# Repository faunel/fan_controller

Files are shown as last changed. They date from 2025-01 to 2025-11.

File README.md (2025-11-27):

English | [Українська](README.uk.md)

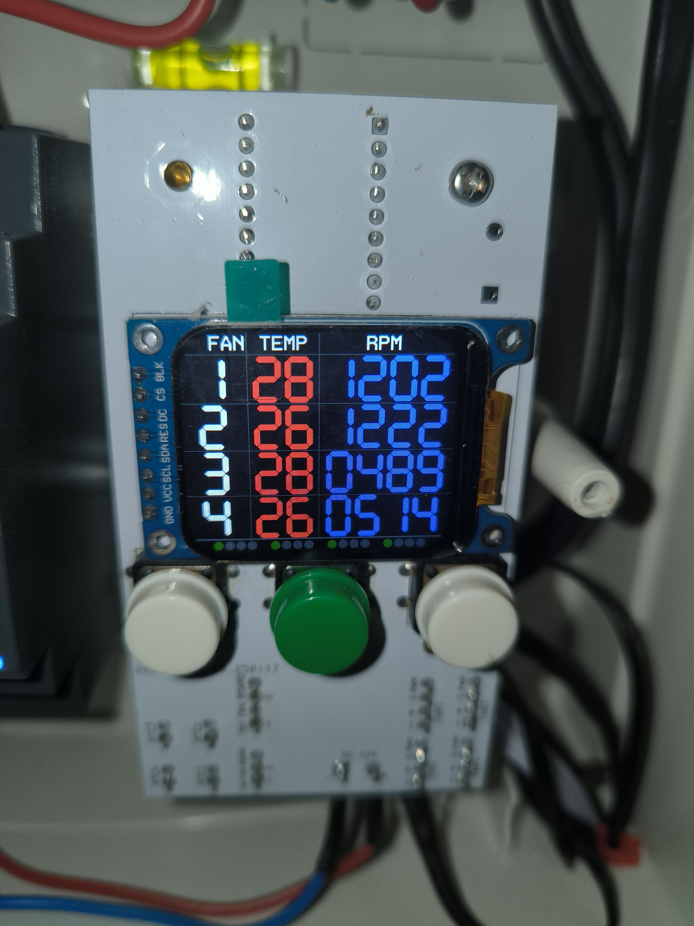
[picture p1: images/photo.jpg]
Fan Controller Board


# PWM Fan Controller Board

A control board for regulating fan speed using PWM (Pulse-Width Modulation).

## Overview

This board is designed to control up to four fans based on temperature readings from up to four NTC thermistors.  
It is intended, in particular, for use with hybrid inverters and includes an inverter fan emulation mode.

- Total output current: up to **5 A**, sufficient with a large margin for typical fans
- Temperature sensor type: **NTC 10 kΩ**
- Up to **4 fans** supported
- Up to **4 temperature sensors** supported
- **4 fan speed levels** depending on temperature
- **1 additional default speed** (used when temperature is below the first level)

## Fan–Sensor Mapping

Fan control logic is configurable in the menu:

- Any sensor can control any fan or group of fans
- All combinations are allowed

Examples:

- One sensor controls all 4 fans
- Two sensors:  
  - Sensor 1 controls fans 1–2  
  - Sensor 2 controls fans 3–4
- One sensor controls a single fan, another sensor controls the remaining three, etc.

The main menu displays for each fan/sensor:

- Temperature
- Fan speed (RPM)
- Current speed level (step)

## Hybrid Inverter Integration

The board is designed to work with a hybrid inverter and supports an **inverter fan emulation mode**.

- If the configuration allows the fans to be stopped (note: not all fans support full stop),
  the inverter will **not** generate a “fan stopped” error.
- Emulation is implemented by generating pulses at **300 Hz** on the signal (yellow) wire
  of the fan connector where the inverter’s original fan would normally be connected.

This corresponds to **9000 RPM** of the fan:

- 2 pulses per revolution  
- Formula: `300 / 2 * 60 = 9000`

### Fan Fault Handling

If the configuration requires a fan to rotate but it does not (for example):

- the connector is unplugged,
- the fan is blocked by a foreign object,
- the fan is defective,

then the inverter will detect an error and shut down until the cause is eliminated.  
This behaviour is intentional to prevent inverter overheating.

## Firmware / Development

### Flashing the firmware

```bash
cargo flash --chip stm32f411ceu6 --release
```

### Build and run with active terminal output

```bash
cargo run --release
```

### Build and detach from terminal

```bash
cargo embed --release
```

### Convert to HEX file

```bash
cargo-objcopy target/thumbv7em-none-eabihf/release/two --release -- -O ihex two.hex
```

### Disassembly

```bash
cargo objdump --bin two --release -- --disassemble --no-show-raw-insn --print-imm-hex
```

### Start OpenOCD

```bash
openocd -f interface/stlink.cfg -f target/stm32f4x.cfg
```

### Check program size

```bash
cargo size --bin fan_controller --release -- -A
```

## Memory Layout

### Program memory (Flash, base address: `0x08000000`)

- `.vector_table` – interrupt vector table, usually at the beginning of memory, containing addresses of interrupt handlers
- `.text` – section with program machine code (instructions)
- `.rodata` – section for constant, read-only data

### RAM (base address: `0x20000000`)

- `.data` – global and static variables initialized to specific values
- `.bss` – global and static variables initialized to zero
- `.uninit` – variables that are not initialized at program start

### Sections not included in the final binary / not critical for runtime

- `.gnu.sgstubs` – may contain special GNU-specific stubs
- `.ARM.attributes` – ARM-architecture-specific attributes
- `.comment` – comments or metadata
- `.defmt` – data for formatted output (e.g., for the `defmt` library)

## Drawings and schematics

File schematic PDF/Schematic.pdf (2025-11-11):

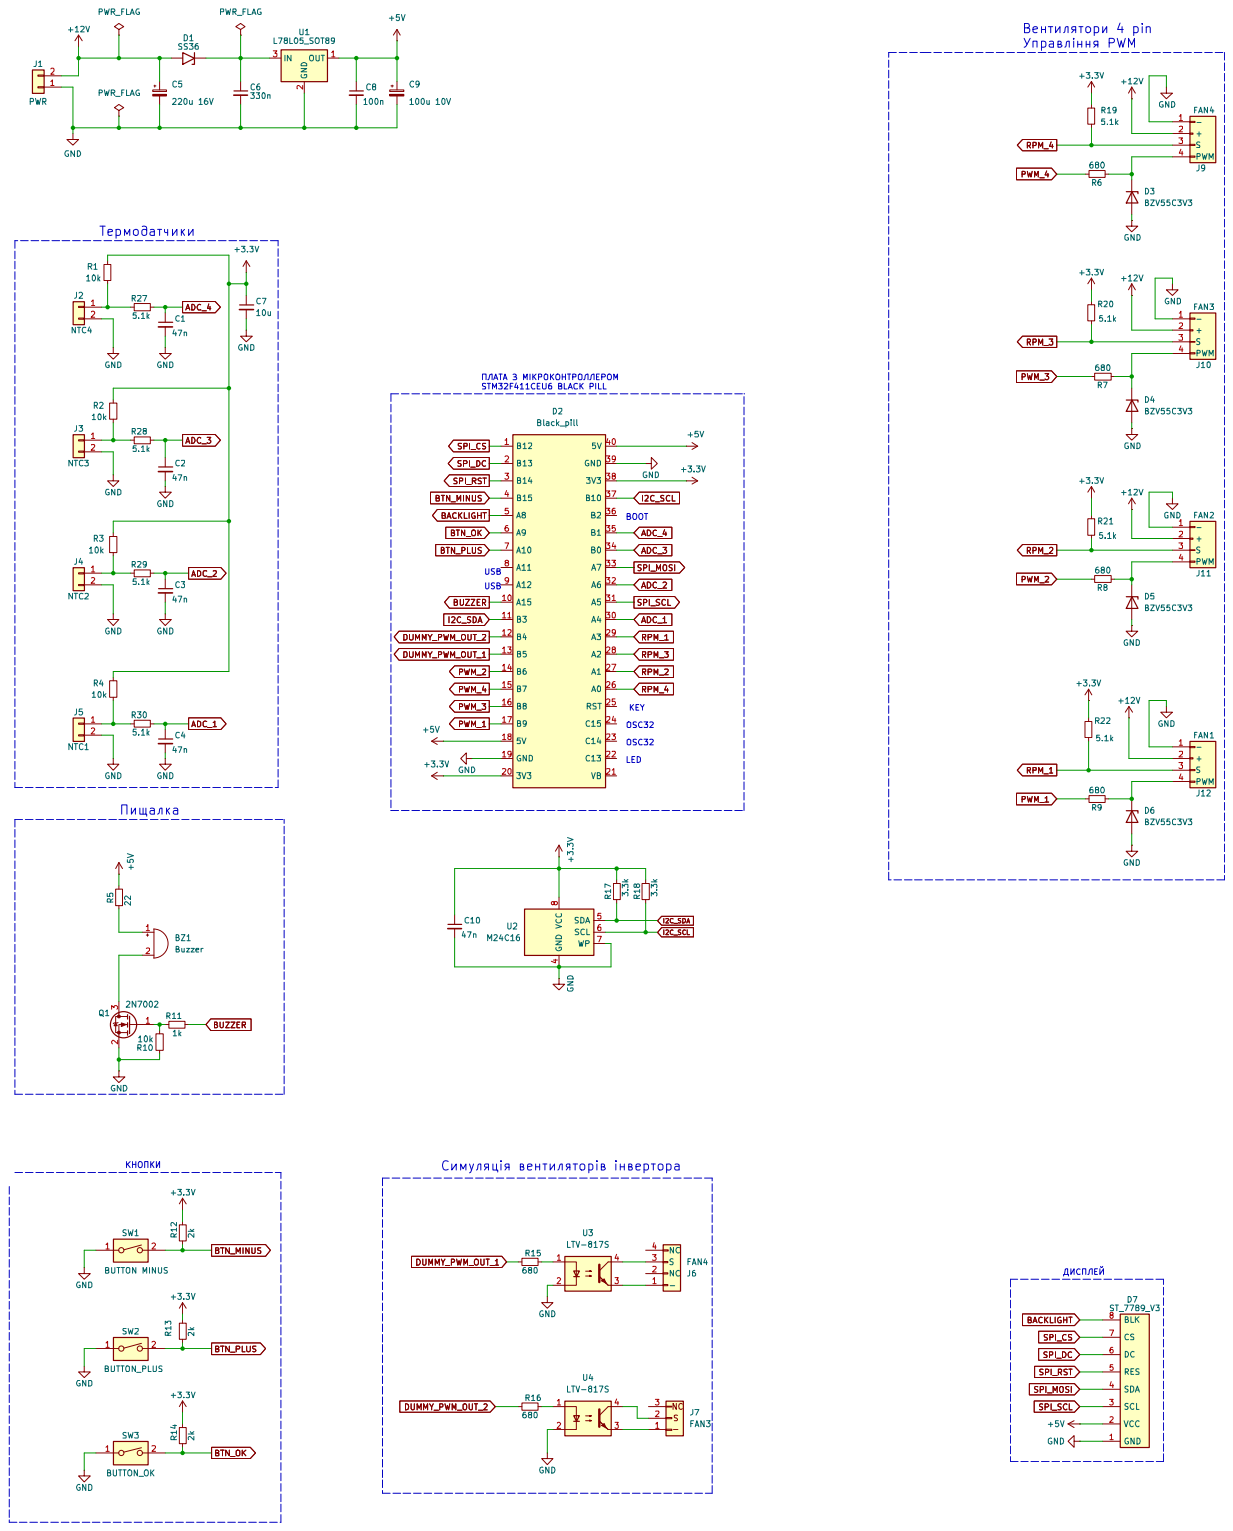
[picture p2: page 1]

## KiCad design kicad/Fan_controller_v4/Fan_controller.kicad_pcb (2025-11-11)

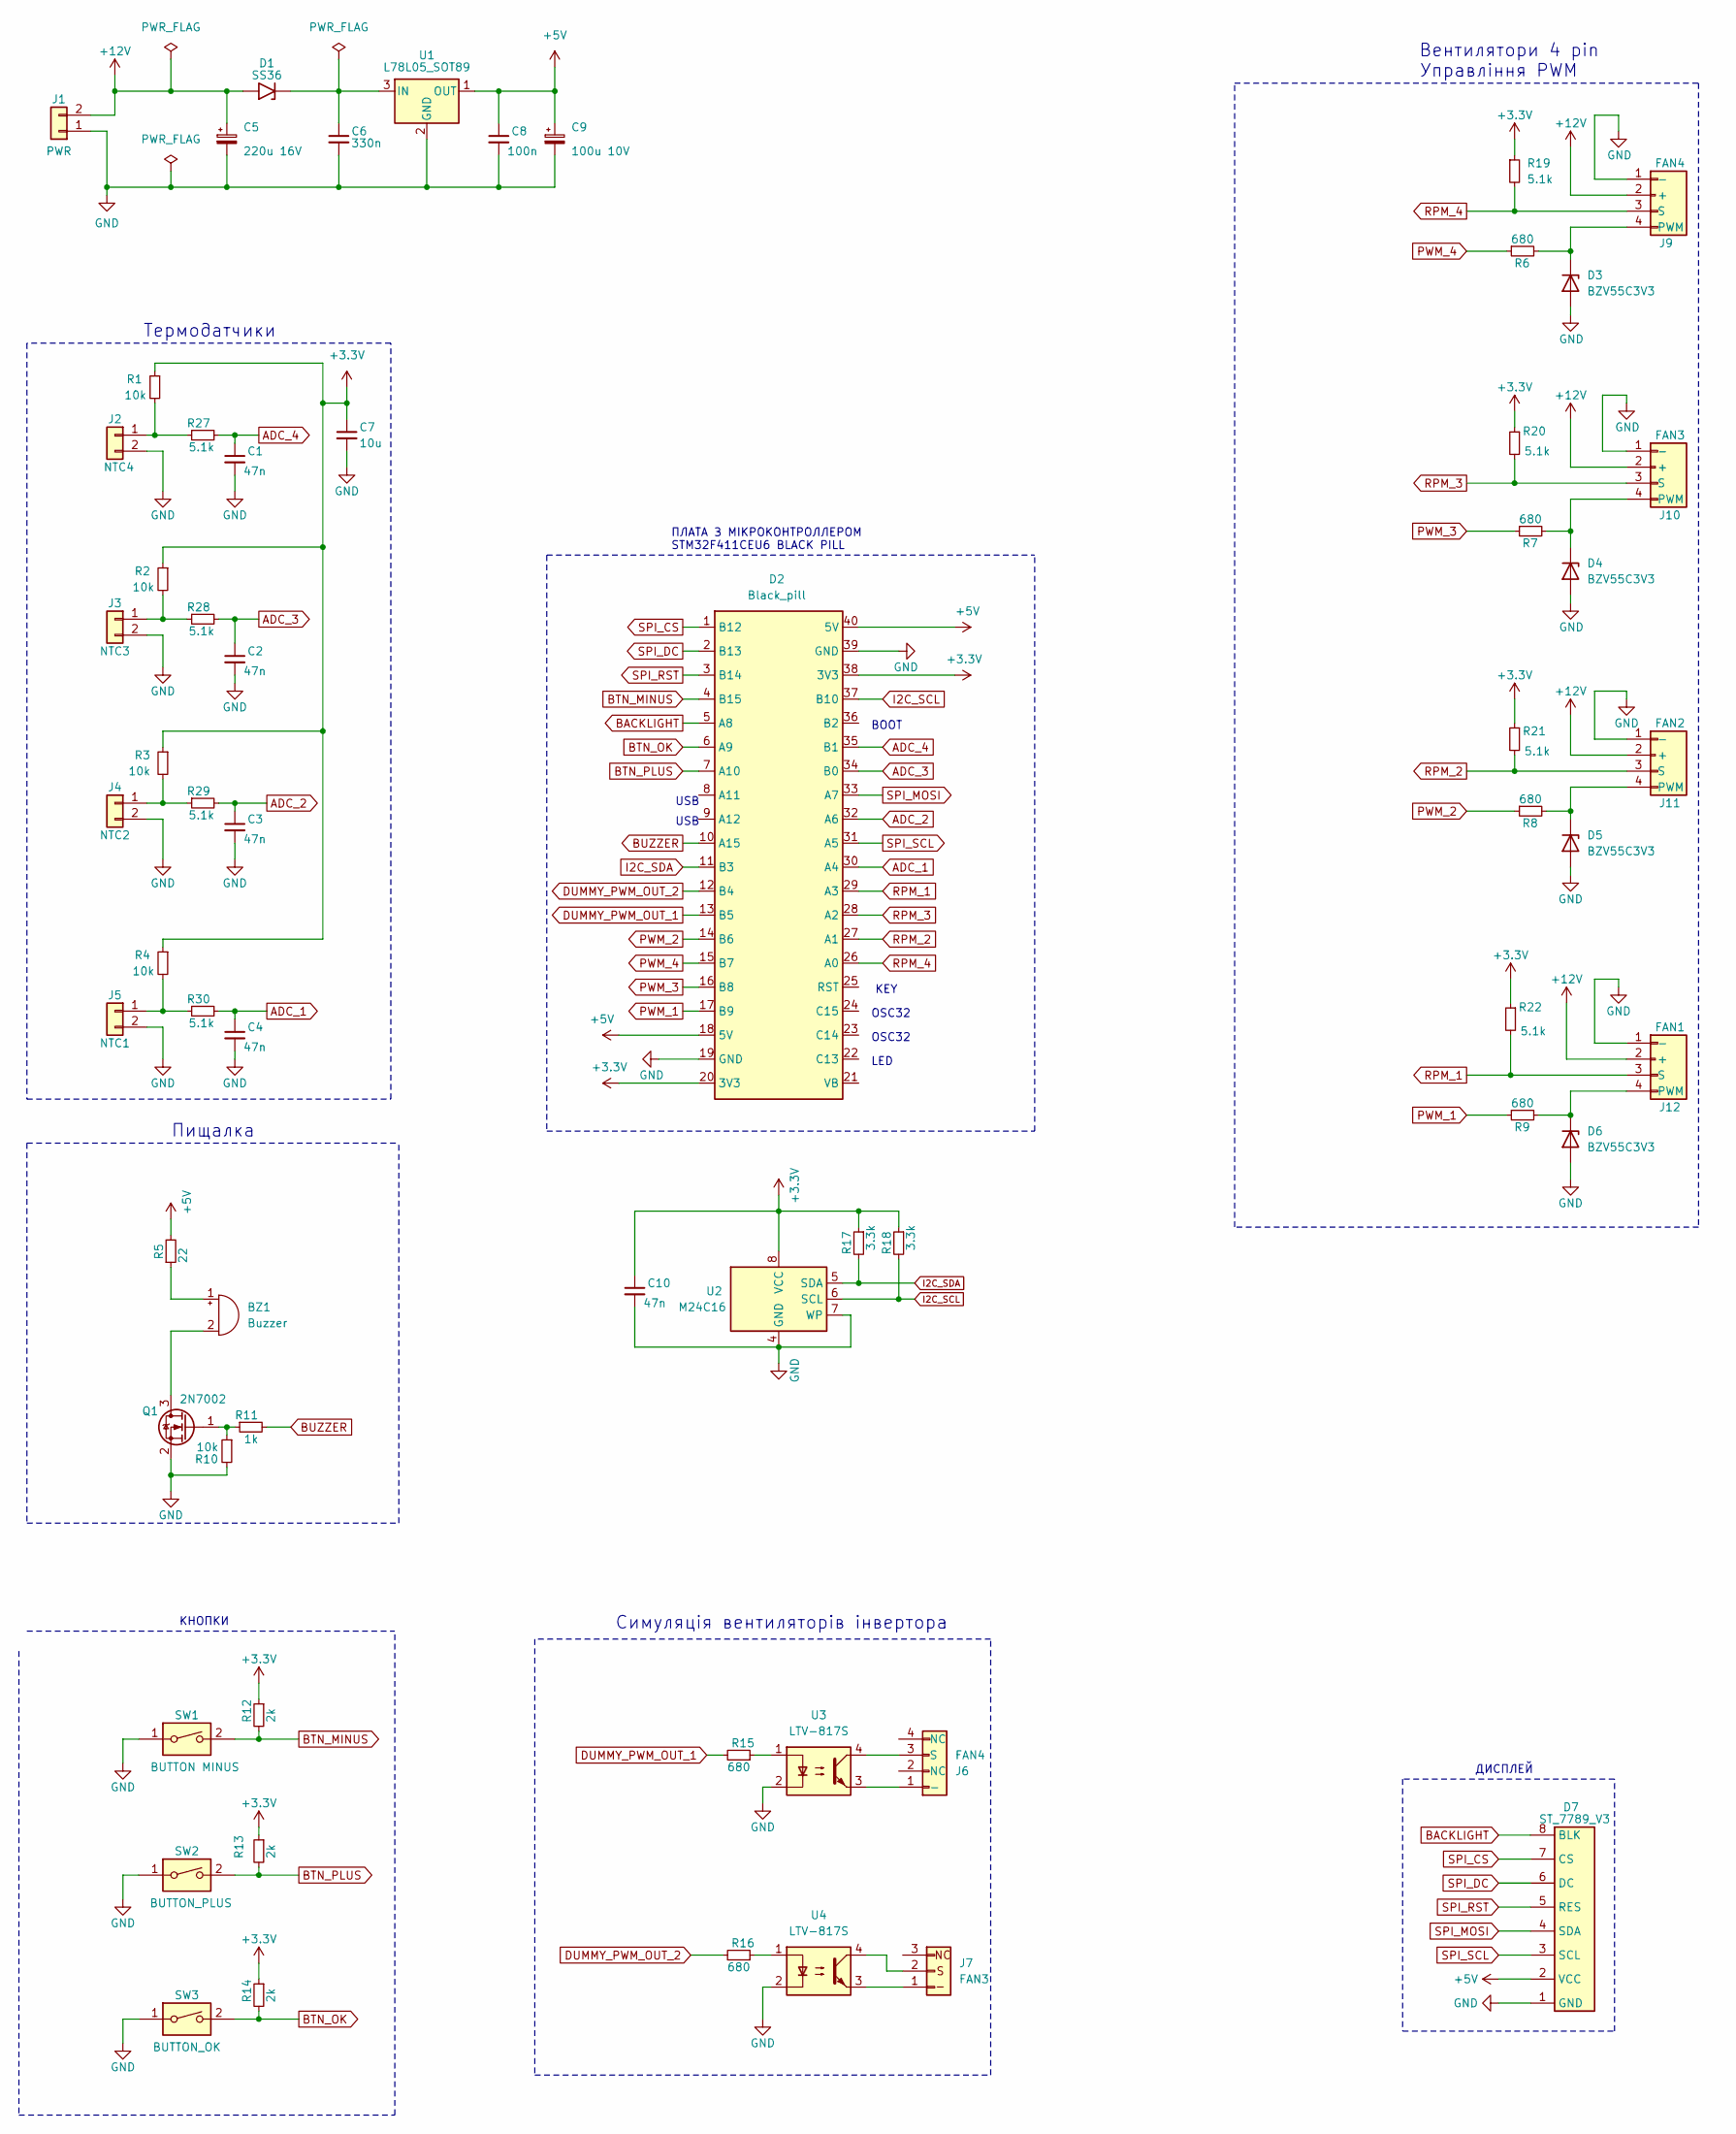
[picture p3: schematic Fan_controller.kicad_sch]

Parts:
BZ1: Buzzer; Buzzer_12x9.5RM7.6
C1, C2, C3, C4, C10: 47n; C_0805_2012Metric_Pad1.18x1.45mm_HandSolder
C5: 220u 16V; CP_Elec_6.3x7.7
C6: 330n; C_0805_2012Metric_Pad1.18x1.45mm_HandSolder
C7: 10u; C_0805_2012Metric_Pad1.18x1.45mm_HandSolder
C8: 100n; C_0805_2012Metric_Pad1.18x1.45mm_HandSolder
C9: 100u 10V; CP_Elec_5x5.4
D1: SS36; D_SMA-SMB_Universal_Handsoldering
D2: Black_pill
D3, D4, D5, D6: BZV55C3V3; D_SOD-123
D7: ST_7789_V3
J1: PWR; TerminalBlock_MetzConnect_Type094_RT03502HBLU_1x02_P5.00mm_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
J2: NTC4; JST_XH_B2B-XH-A_1x02_P2.50mm_Vertical
J3: NTC3; JST_XH_B2B-XH-A_1x02_P2.50mm_Vertical
J4: NTC2; JST_XH_B2B-XH-A_1x02_P2.50mm_Vertical
J5: NTC1; JST_XH_B2B-XH-A_1x02_P2.50mm_Vertical
J6: FAN4; JST_XH_B4B-XH-A_1x04_P2.50mm_Vertical
J7: FAN3; JST_XH_B3B-XH-A_1x03_P2.50mm_Vertical
J9: FAN4; FanPinHeader_1x04_P2.54mm_Vertical
J10: FAN3; FanPinHeader_1x04_P2.54mm_Vertical
J11: FAN2; FanPinHeader_1x04_P2.54mm_Vertical
J12: FAN1; FanPinHeader_1x04_P2.54mm_Vertical
Q1: 2N7002; SOT-23
R1, R2, R3, R4, R10: 10k; R_0805_2012Metric_Pad1.20x1.40mm_HandSolder
R5: 22; R_0805_2012Metric_Pad1.20x1.40mm_HandSolder
R6, R7, R8, R9, R15, R16: 680; R_0805_2012Metric_Pad1.20x1.40mm_HandSolder
R11: 1k; R_0805_2012Metric_Pad1.20x1.40mm_HandSolder
R12, R13, R14: 2k; R_0805_2012Metric_Pad1.20x1.40mm_HandSolder
R17, R18: 3.3k; R_0805_2012Metric_Pad1.20x1.40mm_HandSolder
R19, R20, R21, R22, R27, R28, R29, R30: 5.1k; R_0805_2012Metric_Pad1.20x1.40mm_HandSolder
SW1: BUTTON MINUS; SW_PUSH-12mm
SW2: BUTTON_PLUS; SW_PUSH-12mm
SW3: BUTTON_OK; SW_PUSH-12mm
U1: L78L05_SOT89; SOT-89-3
U2: M24C16; SOIC-8_3.9x4.9mm_P1.27mm
U3, U4: LTV-817S; SMDIP-4_W9.53mm

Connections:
+3.3V: C7.1, C10.1, D2.20 (3V3), D2.38 (3V3), R1.1, R2.1, R3.1, R4.1, R12.1, R13.1, R14.1, R17.1, R18.1, R19.1, R20.1, R21.1, R22.1, U2.8 (VCC)
+5V: C8.1, C9.1, D2.18 (5V), D2.40 (5V), D7.2 (VCC), R5.2, U1.1 (OUT)
+12V: C5.1, D1.2 (A2), J1.2, J9.2 (+), J10.2 (+), J11.2 (+), J12.2 (+)
ADC_1: C4.1, D2.30 (A4), R30.2
ADC_2: C3.1, D2.32 (A6), R29.2
ADC_3: C2.1, D2.34 (B0), R28.2
ADC_4: C1.1, D2.35 (B1), R27.2
BACKLIGHT: D2.5 (A8), D7.8 (BLK)
BTN_MINUS: D2.4 (B15), R12.2, SW1.2
BTN_OK: D2.6 (A9), R14.2, SW3.2
BTN_PLUS: D2.7 (A10), R13.2, SW2.2
BUZZER: D2.10 (A15), R11.2
DUMMY_PWM_OUT_1: D2.13 (B5), R15.2
DUMMY_PWM_OUT_2: D2.12 (B4), R16.2
GND: C1.2, C2.2, C3.2, C4.2, C5.2, C6.2, C7.2, C8.2, C9.2, C10.2, D2.19 (GND), D2.39 (GND), D3.2 (A), D4.2 (A), D5.2 (A), D6.2 (A), D7.1 (GND), J1.1, J2.2, J3.2, J4.2, J5.2, J9.1 (-), J10.1 (-), J11.1 (-), J12.1 (-), Q1.2 (S), R10.2, SW1.1, SW2.1, SW3.1, U1.2 (GND), U2.4 (GND), U2.7 (WP), U3.2, U4.2
I2C_SCL: D2.37 (B10), R18.2, U2.6 (SCL)
I2C_SDA: D2.11 (B3), R17.2, U2.5 (SDA)
unnamed: BZ1.2 (+), Q1.3 (D)
unnamed: BZ1.1 (-), R5.1
unnamed: C6.1, D1.1 (A1), U1.3 (IN)
unnamed: D3.1 (K), J9.4 (PWM), R6.2
unnamed: D4.1 (K), J10.4 (PWM), R7.2
unnamed: D5.1 (K), J11.4 (PWM), R8.2
unnamed: D6.1 (K), J12.4 (PWM), R9.2
unnamed: J2.1, R1.2, R27.1
unnamed: J3.1, R2.2, R28.1
unnamed: J4.1, R3.2, R29.1
unnamed: J5.1, R4.2, R30.1
unnamed: J6.1 (-), U3.3
unnamed: J6.3 (S), U3.4
unnamed: J7.1 (NC), U4.3
unnamed: J7.2, U4.4
unnamed: Q1.1 (G), R10.1, R11.1
unnamed: R15.1, U3.1
unnamed: R16.1, U4.1
PWM_1: D2.17 (B9), R9.1
PWM_2: D2.14 (B6), R8.1
PWM_3: D2.16 (B8), R7.1
PWM_4: D2.15 (B7), R6.1
RPM_1: D2.29 (A3), J12.3 (S), R22.2
RPM_2: D2.27 (A1), J11.3 (S), R21.2
RPM_3: D2.28 (A2), J10.3 (S), R20.2
RPM_4: D2.26 (A0), J9.3 (S), R19.2
SPI_CS: D2.1 (B12), D7.7 (CS)
SPI_DC: D2.2 (B13), D7.6 (DC)
SPI_MOSI: D2.33 (A7), D7.4 (SDA)
SPI_RST: D2.3 (B14), D7.5 (RES)
SPI_SCL: D2.31 (A5), D7.3 (SCL)

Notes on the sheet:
OSC32
ДИСПЛЕЙ
USB
КНОПКИ
ПЛАТА З МІКРОКОНТРОЛЛЕРОМ STM32F411CEU6 BLACK PILL
KEY
LED
Пищалка
Вентилятори 4 pin Управління PWM
BOOT
Симуляція вентиляторів інвертора
Термодатчики

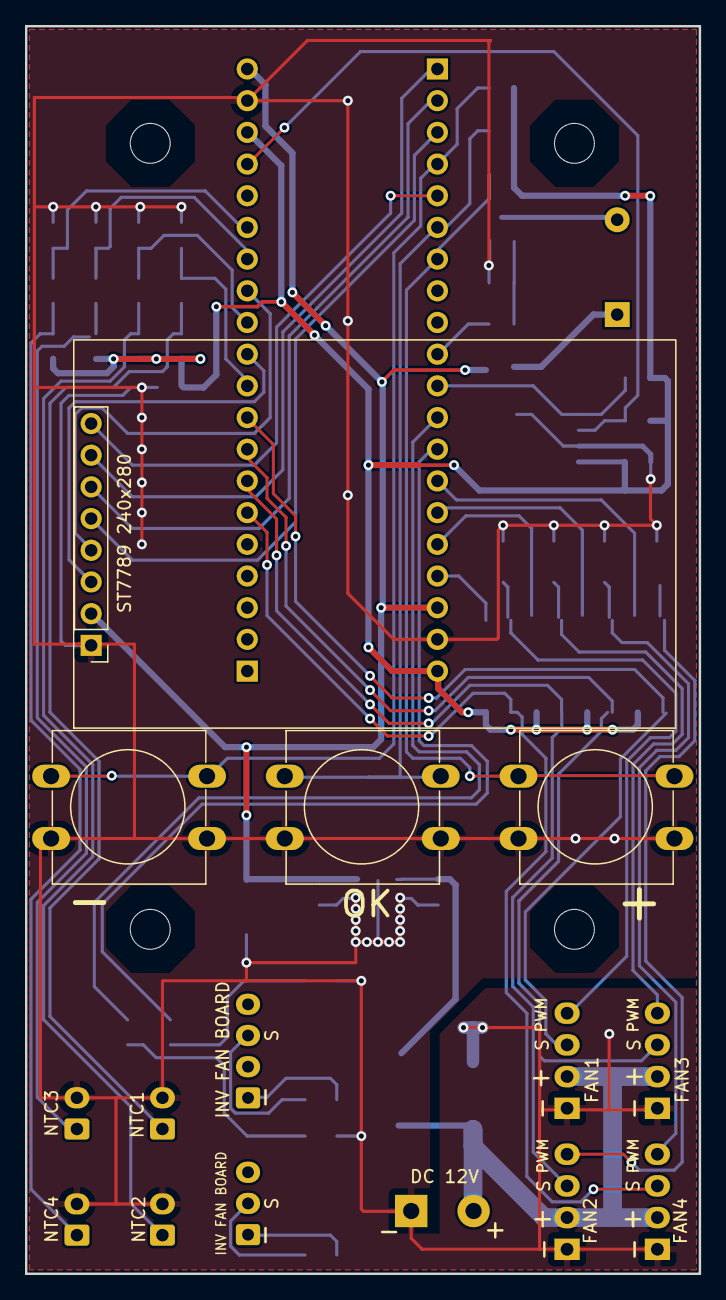
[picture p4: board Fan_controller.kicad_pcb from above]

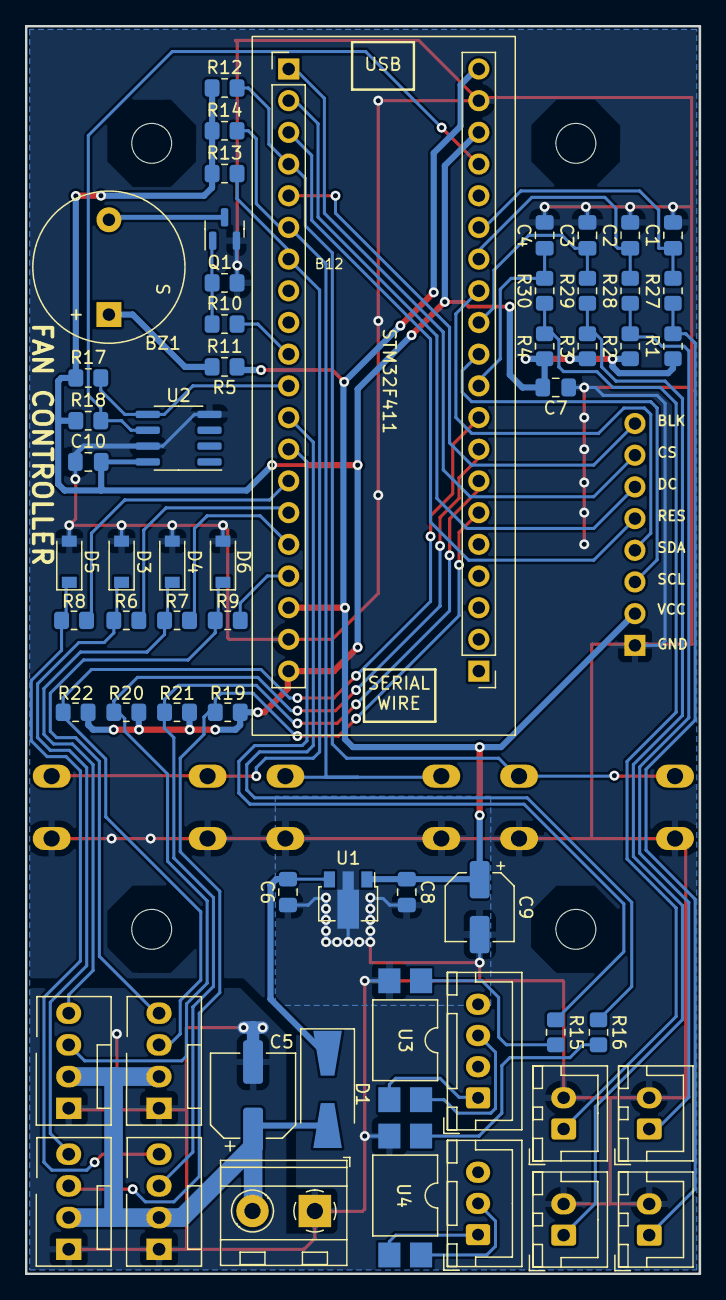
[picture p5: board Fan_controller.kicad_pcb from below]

Board: 2 copper layers, 54.0 x 100.0 mm, 63 parts (59 on the bottom side), 48 nets.

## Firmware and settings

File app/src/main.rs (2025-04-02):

#![no_main]
#![no_std]
// #![allow(unused)]

#[rtic::app(device = stm32f4xx_hal::pac, dispatchers = [SPI2, SPI3, SPI4])]
mod app {
    use async_button::prelude::*;
    // use cortex_m::asm;
    // #[allow(unused)]
    use defmt::info;
    // use display_interface_spi::SPIInterface;
    use eeprom::eeprom::{Settings, EEPROM};
    use embassy_futures::select::{select3, Either3};
    use embedded_alloc::LlffHeap as Heap;
    use embedded_hal::digital::InputPin;
    use embedded_hal_bus::spi::ExclusiveDevice;
    use measurements::{
        control::Control,
        measure::{AdcMeasure, Data, MeasureConfig, RpmData, RpmState},
        ADC_BUFFER,
    };
    use mipidsi::interface::SpiInterface;
    use mipidsi::{models::ST7789, options::ColorInversion};
    use mipidsi::{
        // interface::SpiError as DisplayError,
        // s::Error as DisplayError,
        options::{ColorOrder, Orientation, Rotation},
        Builder,
    };
    use monotonic::prelude::*;
    use ntc::Ntc;
    use rclite::Rc;
    extern crate alloc;
    use defmt_rtt as _;
    use panic_probe as _;
    use spin::rwlock::RwLock;
    #[allow(unused)]
    use stm32f4xx_hal::pac::DWT;
    use stm32f4xx_hal::{
        adc::{
            config::{AdcConfig, Clock, Continuous, Dma, Resolution, SampleTime, Scan, Sequence},
            Adc,
        },
        dma::{config::DmaConfig, PeripheralToMemory, Stream0, StreamsTuple, Transfer},
        gpio::{Pin, Speed},
        hal::pwm::SetDutyCycle,
        i2c::{self, I2c},
        pac::{ADC1, DMA2, TIM1, TIM11, TIM3, TIM5},
        prelude::*,
        rcc::RccExt,
        spi::{Mode, NoMiso, Phase, Polarity, Spi},
        timer::{self, Event, Flag, PwmChannel, Timer},
        watchdog::IndependentWatchdog,
    };
    use stm32f4xx_hal::{
        gpio::{Analog, Input, Output, PinState, Pull},
        timer::{CaptureChannel, CaptureHzManager, CounterHz},
    };
    use ui::Display;
    use ui::{
        fan::FanScreen,
        screens::{settings::SettingsScreen, ItemSetting},
    };
    use ui::{
        main::MainScreen,
        screens::{start::StartScreen, Screen, Screens},
        Menu,
    };

    // use stm32ral::{gpio, rcc, spi::SPI1};
    // use stm32ral::{modify_reg, read_reg, reset_reg, write_reg};

    type DMATransfer = Transfer<Stream0<DMA2>, 0, Adc<ADC1>, PeripheralToMemory, &'static mut [u16; ADC_BUFFER]>;

    #[shared]
    struct Shared {
        data: Data,
        transfer: DMATransfer,
        menu: Menu,
        settings: Settings,
        item_setting: ItemSetting,
        is_clear: bool,
        no_click_timer: Option<u8>,
        adc_buffer: Option<[u16; ADC_BUFFER]>,
        control: Control,
        rpm_data: [RpmData; 4],
        // pwm_input_one: PwmInputOne,
        // pwm_input_two: PwmInputTwo,
        // duty_cycle_fan1: u8,
        // duty_cycle_fan2: u8,
    }

    #[local]
    struct Local {
        rpm_tim: CaptureHzManager<TIM5>,
        rpm_channels: (CaptureChannel<TIM5, 3>, CaptureChannel<TIM5, 1>, CaptureChannel<TIM5, 2>, CaptureChannel<TIM5, 0>),
        tim_11: CounterHz<TIM11>,
        buffer: Option<&'static mut [u16; ADC_BUFFER]>,
        btn_minus_async: WaitPin<Pin<'B', 15>>,
        btn_ok_async: WaitPin<Pin<'A', 9>>,
        btn_plus_async: WaitPin<Pin<'A', 10>>,
        adc: AdcMeasure,
        eeprom: EEPROM,
        iwdg: IndependentWatchdog,
        bl_tim: timer::PwmChannel<TIM1, 0>,
        rpm_state: [RpmState; 4],
        dummy_fans: (PwmChannel<TIM3, 0>, PwmChannel<TIM3, 1>),
    }

    #[global_allocator]
    static HEAP: Heap = Heap::empty();

    #[init]
    fn init(cx: init::Context) -> (Shared, Local) {
        // Heap config
        {
            use core::mem::MaybeUninit;
            const HEAP_SIZE: usize = 512;
            static mut HEAP_MEM: [MaybeUninit<u8>; HEAP_SIZE] = [MaybeUninit::uninit(); HEAP_SIZE];
            #[allow(static_mut_refs)]
            unsafe {
                HEAP.init(HEAP_MEM.as_ptr() as usize, HEAP_SIZE)
            }
        }

        let dp = cx.device;
        let cp = cx.core;

        // Clock config
        let clocks = dp
            .RCC
            .constrain()
            .cfgr
            .use_hse(25.MHz())
            .require_pll48clk()
            .sysclk(100.MHz())
            .hclk(100.MHz())
            .pclk1(50.MHz())
            .pclk2(100.MHz())
            .freeze();

        // Monotonic timer
        Mono::start(cp.SYST, clocks.sysclk().to_Hz());

        // GPIO
        let gpioa = dp.GPIOA.split();
        let gpiob = dp.GPIOB.split();

        let mut delay = dp.TIM10.delay_us(&clocks);

        // cp.DCB.enable_trace();
        // cp.DWT.enable_cycle_counter();

        // let start = DWT::cycle_count();
        // info!("{}", DWT::cycle_count() - start);

        //---------------------------- Start GPIO config -----------------------
        // SPI1 pin config
        let sck_pin = gpioa.pa5.into_alternate().speed(Speed::VeryHigh);
        let mosi_pin = gpioa.pa7.into_alternate().speed(Speed::VeryHigh);
        let miso_pin = NoMiso::new();
        let rst_pin: Pin<'B', 14, Output> = Output::new(gpiob.pb14, PinState::Low).speed(Speed::Medium);
        let cs_pin: Pin<'B', 12, Output> = Output::new(gpiob.pb12, PinState::Low).speed(Speed::Medium);
        let dc_pin: Pin<'B', 13, Output> = Output::new(gpiob.pb13, PinState::Low).speed(Speed::VeryHigh);

        // I2C2 pin config
        let scl_pin = Input::new(gpiob.pb10, Pull::Up);
        let sda_pin = Input::new(gpiob.pb3, Pull::Up);

        // Button pin config
        let btn_minus_pin = Input::new(gpiob.pb15, Pull::Up);
        let btn_ok_pin: Pin<'A', 9> = Input::new(gpioa.pa9, Pull::Up);
        let btn_plus_pin = Input::new(gpioa.pa10, Pull::Up);

        // Button async wrapper
        let btn_minus_async = WaitPin::new(btn_minus_pin);
        let mut btn_ok_async: WaitPin<Pin<'A', 9>> = WaitPin::new(btn_ok_pin);
        let btn_plus_async = WaitPin::new(btn_plus_pin);

        // Buzzer pin
        let _buzzer_pin: Pin<'A', 15, Output> = Output::new(gpioa.pa15, PinState::Low);

        // Backlight pin
        let backlight_pin = gpioa.pa8;

        // Fan PWM output pin
        let fan1_pwm_pin = gpiob.pb9;
        let fan2_pwm_pin = gpiob.pb6;
        let fan3_pwm_pin = gpiob.pb8;
        let fan4_pwm_pin = gpiob.pb7;

        // Fan RPM input_capture pin
        let fan1_rpm_pin = gpioa.pa3;
        let fan2_rpm_pin = gpioa.pa1;
        let fan3_rpm_pin = gpioa.pa2;
        let fan4_rpm_pin = gpioa.pa0;

        // Fan emulator PWM out pin
        let fan_emulator_pwm1_pin: Pin<'B', 4, Output> = Output::new(gpiob.pb4, PinState::Low);
        let fan_emulator_pwm2_pin: Pin<'B', 5, Output> = Output::new(gpiob.pb5, PinState::Low);

        // ADC pin config
        let ntc1_pin = Analog::new(gpioa.pa4);
        let ntc2_pin = Analog::new(gpioa.pa6);
        let ntc3_pin = Analog::new(gpiob.pb0);
        let ntc4_pin = Analog::new(gpiob.pb1);
        //---------------------------- Finish GPIO config -----------------------

        //---------------------------- Start ADC config -----------------------
        // DMA stream
        let dma = StreamsTuple::new(dp.DMA2);

        // ADC config
        let adc_config = AdcConfig::default()
            .dma(Dma::Continuous)
            .scan(Scan::Enabled)
            .clock(Clock::Pclk2_div_8)
            .continuous(Continuous::Single)
            .resolution(Resolution::Twelve);

        // ADC channel config
        let mut adc = Adc::adc1(dp.ADC1, true, adc_config);
        adc.configure_channel(&ntc1_pin, Sequence::One, SampleTime::Cycles_480);
        adc.configure_channel(&ntc2_pin, Sequence::Two, SampleTime::Cycles_480);
        adc.configure_channel(&ntc3_pin, Sequence::Three, SampleTime::Cycles_480);
        adc.configure_channel(&ntc4_pin, Sequence::Four, SampleTime::Cycles_480);

        // ADC buffers
        let adc_buffer = [0; ADC_BUFFER];
        let first_buffer = cortex_m::singleton!(: [u16; ADC_BUFFER] = [0; ADC_BUFFER]).unwrap();
        let adc_dma_buffer = Some(cortex_m::singleton!(: [u16; ADC_BUFFER] = [0; ADC_BUFFER]).unwrap());

        // DMA config
        let dma_config = DmaConfig::default().transfer_complete_interrupt(true).memory_increment(true).double_buffer(false);

        // DMA transfer
        let transfer = Transfer::init_peripheral_to_memory(dma.0, adc, first_buffer, None, dma_config);
        //---------------------------- Finish ADC config -----------------------

        //---------------------------- Start hardware interrupts -----------------------

        // TIM1. For backlight. PWM output config
        let timer = Timer::new(dp.TIM1, &clocks);
        let (_, (ch1, ..)) = timer.pwm_hz(20.kHz());
        let mut bl_tim: timer::PwmChannel<TIM1, 0> = ch1.with(backlight_pin);
        bl_tim.set_duty(50);
        bl_tim.enable();

        // TIM3. For dummy fan
        let timer = Timer::new(dp.TIM3, &clocks);
        let (_, (ch1, ch2, ..)) = timer.pwm_hz(300.Hz());
        let mut dummy_fan_1 = ch1.with(fan_emulator_pwm1_pin);
        let mut dummy_fan_2 = ch2.with(fan_emulator_pwm2_pin);
        dummy_fan_1.set_duty_cycle_percent(50).unwrap();
        dummy_fan_2.set_duty_cycle_percent(50).unwrap();
        dummy_fan_1.enable();
        dummy_fan_2.enable();

        let dummy_fans = (dummy_fan_1, dummy_fan_2);

        // TIM4. PWM для вентиляторів. PWM output config
        let timer = Timer::new(dp.TIM4, &clocks);
        let (_, (ch1, ch2, ch3, ch4, ..)) = timer.pwm_hz(25.kHz());

        let mut fan2_pwm = ch1.with(fan2_pwm_pin);
        let mut fan4_pwm = ch2.with(fan4_pwm_pin);
        let mut fan3_pwm = ch3.with(fan3_pwm_pin);
        let mut fan1_pwm = ch4.with(fan1_pwm_pin);

        // fan1_pwm.set_polarity(timer::Polarity::ActiveLow);
        // fan2_pwm.set_polarity(timer::Polarity::ActiveLow);
        // fan3_pwm.set_polarity(timer::Polarity::ActiveLow);
        // fan4_pwm.set_polarity(timer::Polarity::ActiveLow);

        fan1_pwm.set_duty(0);
        fan2_pwm.set_duty(0);
        fan3_pwm.set_duty(0);
        fan1_pwm.set_duty(0);

        fan1_pwm.enable();
        fan2_pwm.enable();
        fan3_pwm.enable();
        fan4_pwm.enable();

        let pwm_tim = (fan1_pwm, fan2_pwm, fan3_pwm, fan4_pwm);

        // TIM5 for RPM measure
        let (mut rpm_tim, (tim5_ch1, tim5_ch2, tim5_ch3, tim5_ch4)) = Timer::new(dp.TIM5, &clocks).capture_hz(1.MHz());
        let mut fan4_rpm = tim5_ch1.with(fan4_rpm_pin);
        let mut fan2_rpm = tim5_ch2.with(fan2_rpm_pin);
        let mut fan3_rpm = tim5_ch3.with(fan3_rpm_pin);
        let mut fan1_rpm = tim5_ch4.with(fan1_rpm_pin);

        // Полярність імпульсів
        fan1_rpm.set_polarity(timer::Polarity::ActiveHigh);
        fan2_rpm.set_polarity(timer::Polarity::ActiveHigh);
        fan3_rpm.set_polarity(timer::Polarity::ActiveHigh);
        fan4_rpm.set_polarity(timer::Polarity::ActiveHigh);

        // Дільник імпульсів
        // fan1_rpm.set_prescaler(timer::CapturePrescaler::Eight);
        // fan2_rpm.set_prescaler(timer::CapturePrescaler::Eight);
        // fan3_rpm.set_prescaler(timer::CapturePrescaler::Eight);
        // fan4_rpm.set_prescaler(timer::CapturePrescaler::Eight);

        // Фільтр імпульсів
        fan1_rpm.set_filter(timer::CaptureFilter::FdtsDiv32N8);
        fan2_rpm.set_filter(timer::CaptureFilter::FdtsDiv32N8);
        fan3_rpm.set_filter(timer::CaptureFilter::FdtsDiv32N8);
        fan4_rpm.set_filter(timer::CaptureFilter::FdtsDiv32N8);

        // Вмикаємо обробник переривання для input capture
        rpm_tim.listen(Event::C1);
        rpm_tim.listen(Event::C2);
        rpm_tim.listen(Event::C3);
        rpm_tim.listen(Event::C4);

        // Вмикаємо канали таймера
        fan1_rpm.enable();
        fan2_rpm.enable();
        fan3_rpm.enable();
        fan4_rpm.enable();

        let rpm_channels = (fan1_rpm, fan2_rpm, fan3_rpm, fan4_rpm);

        // ---------------- За допомогою регістрів ------------
        // let mut tim5 = Timer::new(dp.TIM5, &clocks).counter_hz();
        // let ral_tim5 = T5::TIM5::take().unwrap();
        // unsafe { modify_reg!(rcc, RCC, APB1ENR, TIM5EN: Enabled) };
        // modify_reg!(T5, ral_tim5, CCMR1, CC1S: 0b01);
        // modify_reg!(T5, ral_tim5, CCER, CC1E: 1);
        // modify_reg!(T5, ral_tim5, PSC, PSC: 3);
        // modify_reg!(T5, ral_tim5, ARR, ARR: 0xFFFFFFFF);
        // modify_reg!(T5, ral_tim5, CR1, URS: 1);
        // write_reg!(T5, ral_tim5, EGR, UG: 1);
        // modify_reg!(T5, ral_tim5, CR1, URS: 0);
        // modify_reg!(T5, ral_tim5, CR1, CEN: 1);
        // modify_reg!(T5, ral_tim5, DIER, CC1IE: Enabled);
        // ---------------------------

        // // Читання значення захоплення
        // let capture_value = tim5.ccr1().read().ccr().bits();

        // let mut tim5 = Timer::new(dp.TIM5, &clocks).counter_hz();
        // tim5.listen(Event::C1);

        // tim5.

        // let (mng, (ch1, ..)) = tim5.pwm_hz(10.kHz());
        // let ch1 = ch1.with(pwm1_in);
        // mng.
        // let mut timer = Timer::new(dp.TIM5, &clocks);
        // let t = timer.counter_hz().configure(&clocks);

        // timer.start(1.MHz()).unwrap();
        // timer.set_master_mode(TIM1::c);
        // timer.listen(Event::C1);

        // let mut counter = timer.counter_hz();
        // counter.start(1.MHz()).unwrap();
        // counter.

        // t.start(1.MHz());
        // timer.listen(Event::C1);
        // timer.

        // TIM11. Для запуску АЦП. Update interrupt config
        // Викликати не частіше 10ms
        let timer: Timer<TIM11> = Timer::new(dp.TIM11, &clocks);
        let mut tim_11: CounterHz<TIM11> = timer.counter_hz();
        tim_11.start(100.Hz()).unwrap();
        tim_11.listen(Event::Update);
        //---------------------------- Finish hardware interrupts -----------------------

        // SPI2 mode configuration
        let mode = Mode {
            polarity: Polarity::IdleLow,
            phase: Phase::CaptureOnFirstTransition,
        };

        // SPI interface
        let spi_buffer: &'static mut [u8; 512] = cortex_m::singleton!(: [u8; 512] = [0; 512]).unwrap();

        let spi = Spi::new(dp.SPI1, (sck_pin, miso_pin, mosi_pin), mode, 48.MHz(), &clocks);
        let device = ExclusiveDevice::new_no_delay(spi, cs_pin).unwrap();
        let interface = SpiInterface::new(device, dc_pin, spi_buffer);

        // Display config
        let display: Display = Builder::new(ST7789, interface)
            .orientation(Orientation {
                rotation: Rotation::Deg90,
                mirrored: false,
            })
            .display_offset(0, 20)
            .color_order(ColorOrder::Rgb)
            .invert_colors(ColorInversion::Inverted)
            .reset_pin(rst_pin)
            .display_size(240, 280)
            .init(&mut delay)
            .unwrap();

        let ntc = Ntc::default();
        let measure_config = MeasureConfig {
            temp_ema_window: 20,
            rpm_ema_window: 20,
        };
        let data = Data::new(ntc, measure_config);

        // Tasks
        eeprom_task::spawn(&mut btn_ok_async, display).ok();
        data_task::spawn().unwrap();
        clear_rpm_task::spawn().unwrap();

        // Ці задачі повинні бути створені після задачі "eeprom_task"
        // Це пояснюється тим, що для цих задач структура settings повинна бути з даними, отриманими з EEPROM

        // display_menu_task::spawn(display).ok();
        // button_task::spawn().unwrap();
        // backlight_task::spawn().unwrap();
        // pwm_fan_task::spawn().unwrap();

        (
            Shared {
                data,
                transfer,
                menu: Menu::Main,
                settings: Settings::new(),
                item_setting: ItemSetting::Item(1),
                is_clear: true,
                no_click_timer: None,
                adc_buffer: Some(adc_buffer),
                control: Control::new(pwm_tim),
                rpm_data: RpmData::new(),
                // pwm_input_one,
                // pwm_input_two,
                // duty_cycle_fan1: 200,
                // duty_cycle_fan2: 200,
            },
            Local {
                rpm_tim,
                rpm_channels,
                tim_11,
                buffer: adc_dma_buffer,
                btn_minus_async,
                btn_ok_async,
                btn_plus_async,
                adc: AdcMeasure::new(),
                eeprom: EEPROM::new(I2c::new(dp.I2C2, (scl_pin, sda_pin), i2c::Mode::standard(100.kHz()), &clocks)),
                iwdg: IndependentWatchdog::new(dp.IWDG),
                bl_tim,
                rpm_state: RpmState::new(),
                dummy_fans,
            },
        )
    }

    // #[task(shared = [eeprom, settings], priority = 2)]
    // async fn default_settings_task(mut cx: default_settings_task::Context, btn_ok_async: &mut WaitPin<Pin<'B', 14>>) {
    //     if btn_ok_async.is_low().unwrap_or(false) {
    //         Mono::delay(2000.millis()).await;
    //         if btn_ok_async.is_low().unwrap_or(false) {
    //             let mut s = cx.shared.settings.lock(move |settings| settings.clone());
    //             cx.local.eeprom.default_settings(&mut s).await;
    //             cx.shared.settings.lock(|settings| {
    //                 *settings = s;
    //             });
    //         }
    //     }
    // }

    #[task(local = [dummy_fans], shared = [rpm_data, control], priority = 2)]
    async fn clear_rpm_task(mut cx: clear_rpm_task::Context) {
        loop {
            cx.shared.rpm_data.lock(|rpm_data| {
                rpm_data.iter_mut().for_each(|r| r.clear_active_fans());
            });
            Mono::delay(2000.millis()).await;

            cx.shared.rpm_data.lock(|rpm_data| {
                if !rpm_data[0].is_active_fan() {
                    rpm_data[0].clear_rpm();
                    cx.shared.control.lock(|control| {
                        let duty = control.get_duty_cycle_percent_ch1();
                        if duty > 10 {
                            cx.local.dummy_fans.0.disable();
                        }
                    });
                } else {
                    cx.local.dummy_fans.0.enable();
                }
                if !rpm_data[1].is_active_fan() {
                    rpm_data[1].clear_rpm();
                    cx.shared.control.lock(|control| {
                        let duty = control.get_duty_cycle_percent_ch2();
                        if duty > 10 {
                            cx.local.dummy_fans.1.disable();
                        }
                    });
                } else {
                    cx.local.dummy_fans.1.enable();
                }
                if !rpm_data[2].is_active_fan() {
                    rpm_data[2].clear_rpm();
                }
                if !rpm_data[3].is_active_fan() {
                    rpm_data[3].clear_rpm();
                }
            });
        }
    }

    // Software task
    // Завантажує всі налаштування.
    // Зберігає налаштування при відсутності натискань кнопок за певний період при умові зміни будь якого параметру
    #[task(local = [eeprom], shared = [no_click_timer, settings, menu, is_clear, item_setting], priority = 2)]
    async fn eeprom_task(mut cx: eeprom_task::Context, btn_ok_async: &mut WaitPin<Pin<'A', 9>>, display: Display) {
        if btn_ok_async.is_low().unwrap_or(false) {
            Mono::delay(2000.millis()).await;
            if btn_ok_async.is_low().unwrap_or(false) {
                let mut s = cx.shared.settings.lock(move |settings| settings.clone());
                cx.local.eeprom.default_settings(&mut s).await;
                cx.shared.settings.lock(|settings| {
                    *settings = s;
                });
            }
        }

        let mut s = cx.shared.settings.lock(move |settings| settings.clone());
        cx.local.eeprom.load_settings(&mut s).await;
        cx.shared.settings.lock(|settings| {
            *settings = s;
        });

        button_task::spawn().unwrap();
        backlight_task::spawn().unwrap();
        pwm_fan_task::spawn().unwrap();
        display_menu_task::spawn(display).ok();

        loop {
            let s = cx.shared.no_click_timer.lock(|no_click_timer| {
                if let Some(t) = no_click_timer {
                    *t = t.saturating_sub(1);

                    if *t == 0 {
                        *no_click_timer = None;

                        (&mut cx.shared.menu, &mut cx.shared.is_clear, &mut cx.shared.item_setting).lock(|menu, is_clear, item_setting| {
                            match *menu {
                                Menu::Main => {}
                                _ => {
                                    *menu = Menu::Main;
                                    *is_clear = true;
                                    *item_setting = ItemSetting::Item(1);
                                }
                            }
                        });
                        return Some(cx.shared.settings.lock(|settings| settings.clone()));
                    }
                }
                None
            });

            if let Some(mut s) = s {
                cx.local.eeprom.save_all(&mut s).await;
            }

            Mono::delay(1000.millis()).await;
        }
    }

    // Software task
    // Для відображення даних на дисплеї
    #[task(shared = [menu, data, settings, item_setting, is_clear], priority = 1)]
    async fn display_menu_task(cx: display_menu_task::Context, mut display: Display) {
        let main_screen = Rc::new(RwLock::new(MainScreen::default()));
        let fan_screen = Rc::new(RwLock::new(FanScreen::default()));
        let settings_screen = Rc::new(RwLock::new(SettingsScreen::default()));
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

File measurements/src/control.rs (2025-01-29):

use core::cmp::Ordering;
// use defmt::info;
use eeprom::eeprom::Settings;
use stm32f4xx_hal::{hal::pwm::SetDutyCycle, pac::TIM4, timer};

use crate::measure::Data;

type TimerType = (timer::PwmChannel<TIM4, 3>, timer::PwmChannel<TIM4, 0>, timer::PwmChannel<TIM4, 2>, timer::PwmChannel<TIM4, 1>);

pub struct Control {
    timer: TimerType,
    old_pwm: [u8; 4],
    current_pwm: [u8; 4],
}

impl Control {
    pub fn new(timer: TimerType) -> Self {
        Control {
            timer,
            old_pwm: [0; 4],
            current_pwm: [0; 4],
        }
    }

    pub fn run(&mut self, settings: &Settings, data: &mut Data) {
        let mut thresold: [u8; 4] = [0; 4];
        for (ind_fan, fan) in settings.fans.iter().enumerate() {
            let temp = data.get_temp();
            let ntc_no = settings.ntc_no[ind_fan].data;

            let current_temp = temp[usize::from(ntc_no) - 1];

            // Якщо температура менша ніж перший поріг, зменшуємо PWM до нуля
            if current_temp < fan.thresold[0].temp.data {
                self.current_pwm[ind_fan] = self.current_pwm[ind_fan].saturating_sub(1);
            // Температура в діапазоні від поточного діапазону до наступного
            // В циклі перевіряємо в якому вона діапазоні
            } else {
                for ind_thresold in 0..4 {
                    let set_temp_from = fan.thresold[ind_thresold].temp.data;

                    let set_temp_to = if ind_thresold == 3 {
                        u8::MAX as u16
                    } else {
                        fan.thresold[ind_thresold + 1].temp.data
                    };

                    // current_temp >= set_temp_from && current_temp < set_temp_to
                    if (set_temp_from..set_temp_to).contains(&current_temp) {
                        let set_pwm = fan.thresold[ind_thresold].pwm.data as u8;
                        thresold[ind_fan] = ind_thresold as u8 + 1;

                        match self.current_pwm[ind_fan].cmp(&set_pwm) {
                            // Якщо PWM потрібно більший чим поточний, збільшуємо його
                            Ordering::Less => self.current_pwm[ind_fan] += 1,
                            // Якщо PWM потрібно менший чим поточний, зменшуємо його
                            Ordering::Greater => self.current_pwm[ind_fan] -= 1,
                            Ordering::Equal => {}
                        }
                    }
                }
            }

            if self.old_pwm[ind_fan] != self.current_pwm[ind_fan] {
                // info!("fan: {}, pwm: {}", ind_fan, self.current_pwm[ind_fan]);
                match ind_fan {
                    0 => {
                        // info!("FAN: {}, PWM: {}", ind_fan, self.current_pwm[ind_fan]);
                        self.timer.0.set_duty_cycle_percent(self.current_pwm[ind_fan]).unwrap();
                    }
                    1 => {
                        // info!("FAN: {}, PWM: {}", ind_fan, self.current_pwm[ind_fan]);
                        self.timer.1.set_duty_cycle_percent(self.current_pwm[ind_fan]).unwrap()
                    }
                    2 => self.timer.2.set_duty_cycle_percent(self.current_pwm[ind_fan]).unwrap(),
                    3 => self.timer.3.set_duty_cycle_percent(self.current_pwm[ind_fan]).unwrap(),
                    _ => unreachable!(),
                }
                self.old_pwm[ind_fan] = self.current_pwm[ind_fan];
            }
        }
        data.set_thresold(&thresold);
    }

    pub fn get_duty_cycle_percent_ch1(&self) -> u16 {
        let channel = &self.timer.0;
        let duty = channel.get_duty();
        let max_duty = channel.get_max_duty();
        if duty == 0 {
            return 0;
        }
        100 / (max_duty / duty)
    }

    pub fn get_duty_cycle_percent_ch2(&self) -> u16 {
        let channel = &self.timer.1;
        let duty = channel.get_duty();
        let max_duty = channel.get_max_duty();
        if duty == 0 {
            return 0;
        }
        100 / (max_duty / duty)
    }
}
